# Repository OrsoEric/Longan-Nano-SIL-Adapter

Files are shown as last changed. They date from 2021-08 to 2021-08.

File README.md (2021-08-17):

# Longan-Nano-SIL-Adapter
SIL Adapter for the Longan Nano evaluation board for the GD32VF103. Allows vertical mounting for the board. Includes RS485 communication with 3.5mm Audio Jacks.

**Connector Pinout**  


**Schematics**  
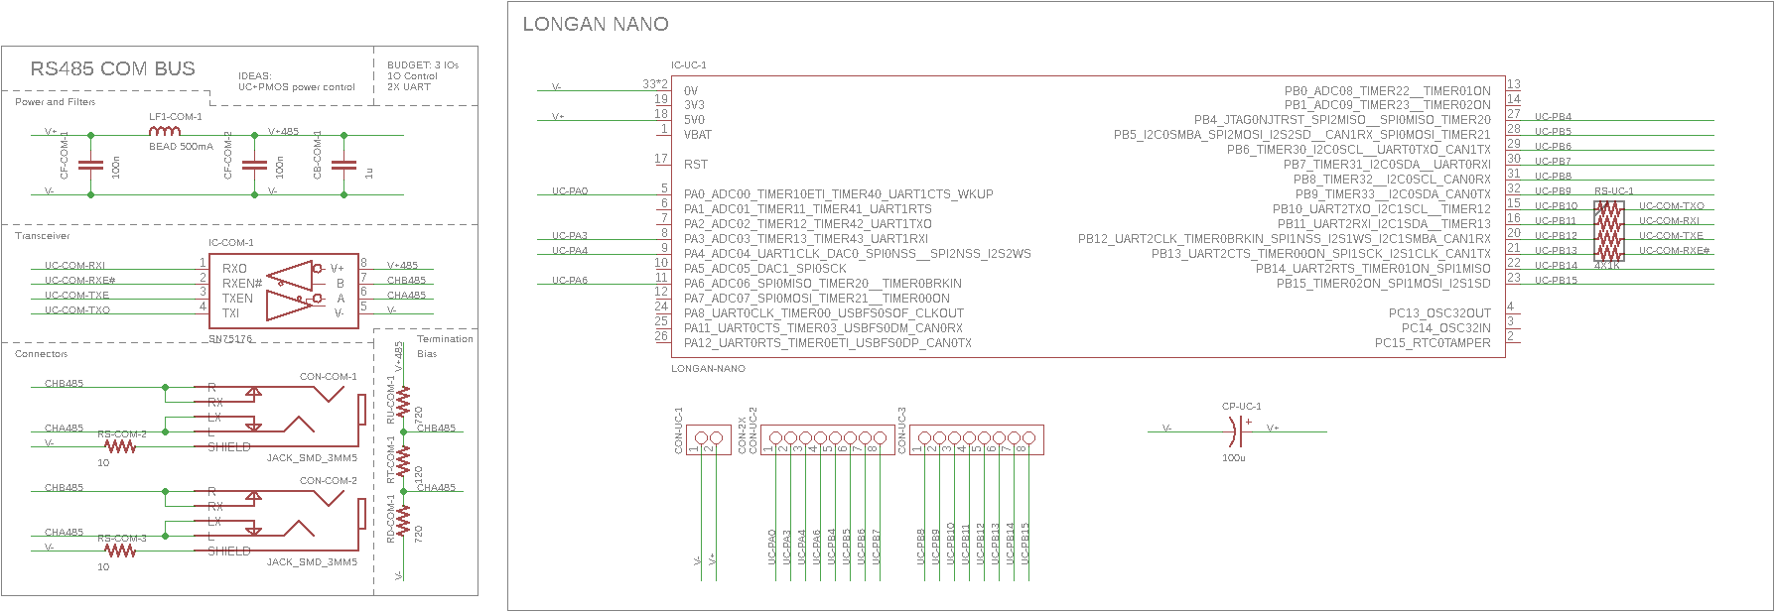
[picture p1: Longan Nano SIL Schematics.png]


**Routing**  


**Gerber**  
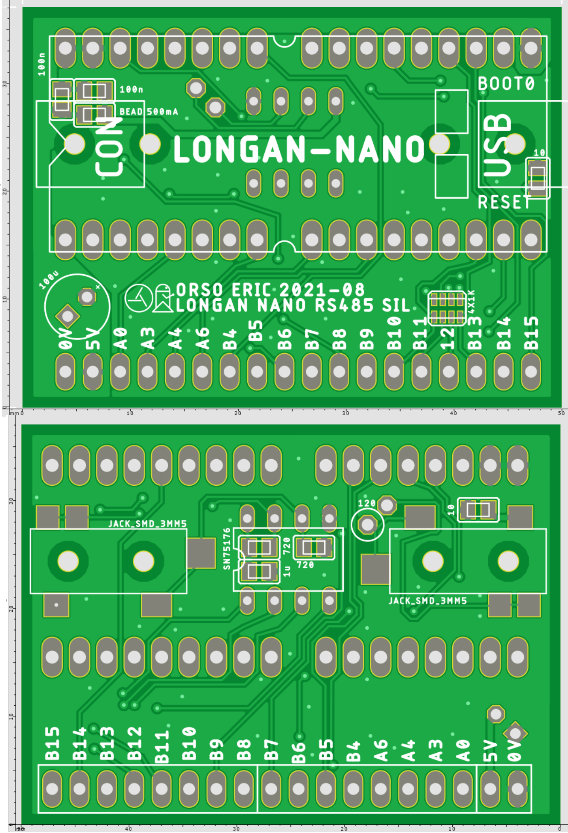
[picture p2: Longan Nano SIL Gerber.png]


**BOM**
*Part* 	*Value*  
CB-COM-1 	1u  
CF-COM-1 	100n  
CF-COM-2 	100n  
CON-COM-1 	JACK_SMD_3MM5  
CON-COM-2 	JACK_SMD_3MM5  
CON-UC-1 	2X2.54mm Male  
CON-UC-2 	8X2.54mm Male  
CON-UC-3 	8X2.54mm Male  
CP-UC-1 	100u  
IC-COM-1 	SN75176  
IC-UC-1 	LONGAN-NANO  
LF1-COM-1 	BEAD 500mA  
RD-COM-1 	720  
RS-COM-2 	10  
RS-COM-3 	10  
RS-UC-1 	4X1K  
RT-COM-1 	120  
RU-COM-1 	720

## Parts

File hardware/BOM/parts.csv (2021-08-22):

Part | Value | Device | Package | Description | MF | MPN | OC_FARNELL | OC_NEWARK
CB-COM-1 | 1u | C-M2012 | SMD-M2012 | Capacitor
CF-COM-1 | 100n | C-M2012 | SMD-M2012 | Capacitor
CF-COM-2 | 100n | C-M2012 | SMD-M2012 | Capacitor
CON-COM-1 | JACK_SMD_3MM5 | JACK_SMD_3MM5 | JACK_SMD_3MM5 | Jack 3.5mm
CON-COM-2 | JACK_SMD_3MM5 | JACK_SMD_3MM5 | JACK_SMD_3MM5 | Jack 3.5mm
CON-UC-1 | 2X2.54mm Male | CON-2X | TH-2X2.54 | Generic connector two pins
CON-UC-2 | 8X2.54mm Male | CON-8X | TH-8X2.54 | PIN HEADER
CON-UC-3 | 8X2.54mm Male | CON-8X | TH-8X2.54 | PIN HEADER
CP-UC-1 | 100u | C+-TH2.54-6.0 | TH-BARREL-2M54-6M0 | Polarized Capacitor
IC-COM-1 | SN75176 | RS485 | DIL08 | RS485 TRANSEIVER |  | MAX481CPA+ | unknown | 99K3445
IC-UC-1 | LONGAN-NANO | LONGAN-NANO | LONGAN-NANO | Longan Nano
LF1-COM-1 | BEAD 500mA | L-M2012 | SMD-M2012 | Inductor
RD-COM-1 | 720 | R-M2012 | SMD-M2012 | Resistor
RS-COM-2 | 10 | R-M2012 | SMD-M2012 | Resistor
RS-COM-3 | 10 | R-M2012 | SMD-M2012 | Resistor
RS-UC-1 | 4X1K | RX4-M2012-X4 | SMD-M2012-X4 | Four Resistor
RT-COM-1 | 120 | R-V2.54-3.0 | TH-LINE-2M54-3M0 | Resistor
RU-COM-1 | 720 | R-M2012 | SMD-M2012 | Resistor

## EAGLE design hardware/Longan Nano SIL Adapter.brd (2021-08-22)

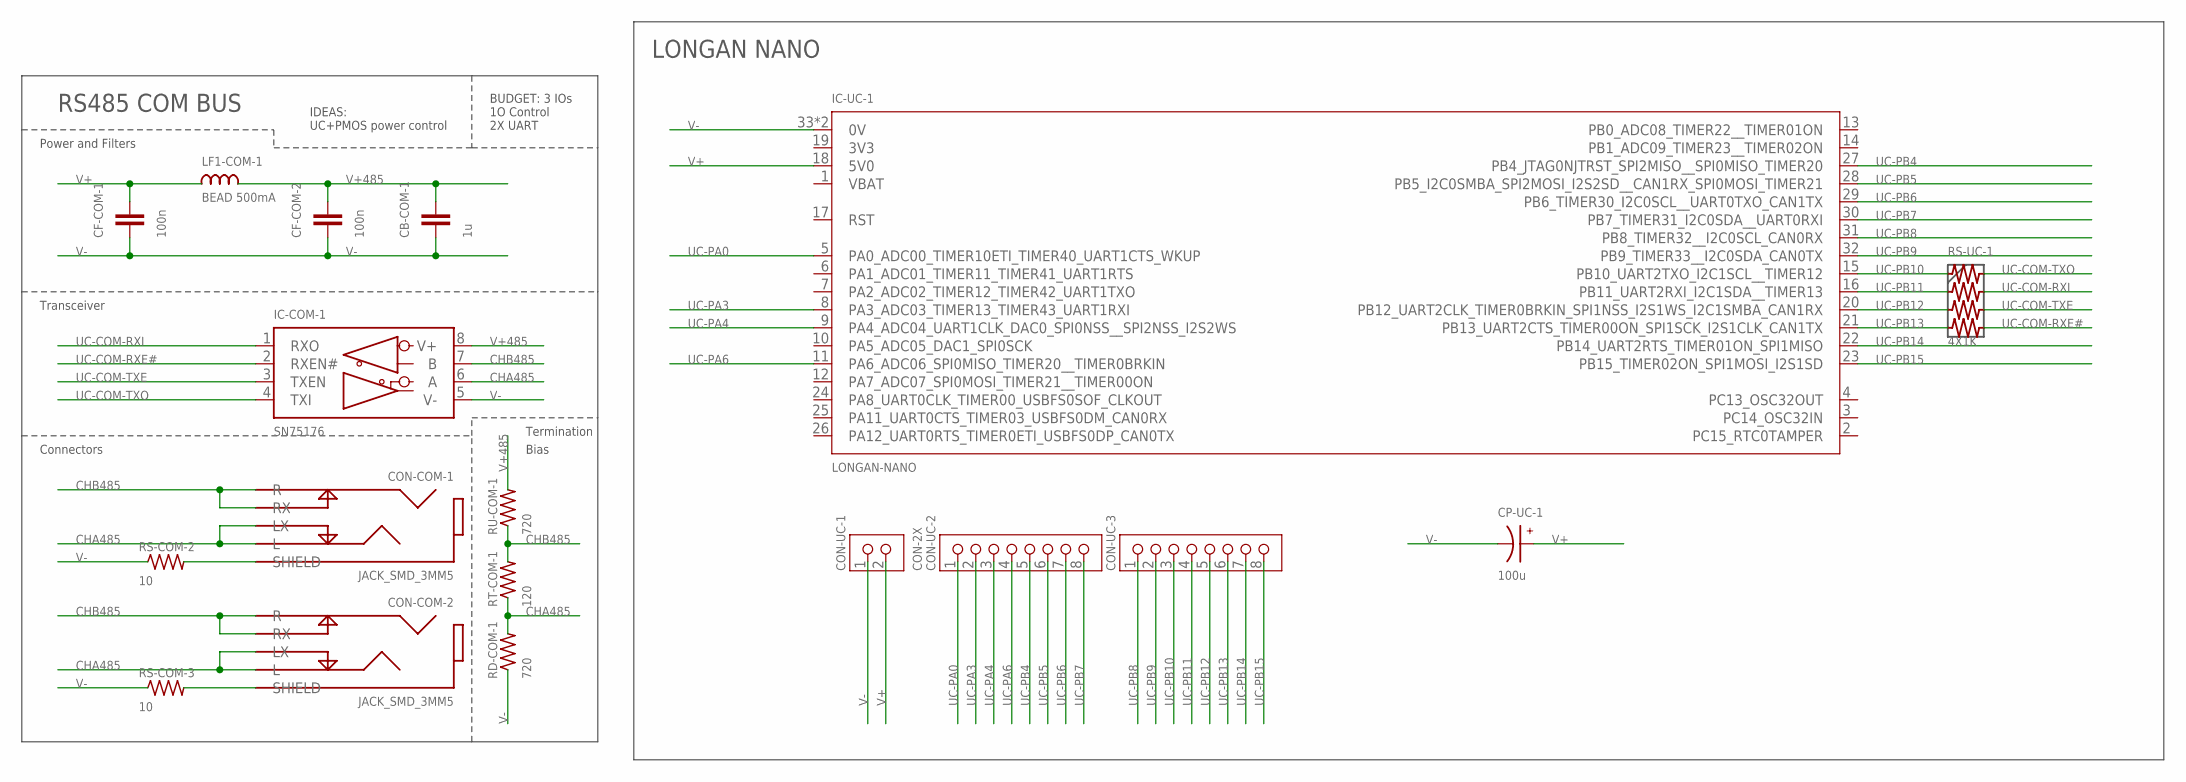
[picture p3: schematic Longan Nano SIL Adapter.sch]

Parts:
CB-COM-1: 1u; SMD-M2012
CF-COM-1, CF-COM-2: 100n; SMD-M2012
CON-COM-1, CON-COM-2: JACK_SMD_3MM5
CON-UC-1: CON-2X; TH-2X2.54
CON-UC-2, CON-UC-3: CON-8X; TH-8X2.54
CP-UC-1: 100u; TH-BARREL-2M54-6M0
IC-COM-1: SN75176; DIL08
IC-UC-1: LONGAN-NANO
LF1-COM-1: BEAD 500mA; SMD-M2012
RD-COM-1: 720; SMD-M2012
RS-COM-2, RS-COM-3: 10; SMD-M2012
RS-UC-1: 4X1K; SMD-M2012-X4
RT-COM-1: 120; TH-LINE-2M54-3M0
RU-COM-1: 720; SMD-M2012

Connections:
3V3: IC-UC-1.19 (3V3)
CHA485: CON-COM-1.L, CON-COM-1.LX, CON-COM-2.L, CON-COM-2.LX, IC-COM-1.6 (A), RD-COM-1.2, RT-COM-1.P$1 (1)
CHB485: CON-COM-1.R, CON-COM-1.RX, CON-COM-2.R, CON-COM-2.RX, IC-COM-1.7 (B), RT-COM-1.P$2 (2), RU-COM-1.1
unnamed: CON-COM-1.SHIELD, RS-COM-2.2
unnamed: CON-COM-2.SHIELD, RS-COM-3.2
UC-COM-RXE#: IC-COM-1.2 (RXEN#), RS-UC-1.4B
UC-COM-RXI: IC-COM-1.1 (RXO), RS-UC-1.2B
UC-COM-TXE: IC-COM-1.3 (TXEN), RS-UC-1.3B
UC-COM-TXO: IC-COM-1.4 (TXI), RS-UC-1.1B
UC-PA0: CON-UC-2.1, IC-UC-1.5 (PA0_ADC00_TIMER10ETI_TIMER40_UART1CTS_W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)
UC-PA3: CON-UC-2.2, IC-UC-1.8 (PA3_ADC03_TIMER13_TIMER43_UART1RXI)
UC-PA4: CON-UC-2.3, IC-UC-1.9 (PA4_ADC04_UART1CLK_DAC0_SPI0NSS__SPI2NS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)
UC-PA6: CON-UC-2.4, IC-UC-1.11 (PA6_ADC06_SPI0MISO_TIMER20__TIMER0BRKIN)
UC-PB4: CON-UC-2.5, IC-UC-1.27 (PB4_JTAG0NJTRST_SPI2MISO__SPI0MISO_TIME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)
UC-PB5: CON-UC-2.6, IC-UC-1.28 (PB5_I2C0SMBA_SPI2MOSI_I2S2SD__CAN1RX_SP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)
UC-PB6: CON-UC-2.7, IC-UC-1.29 (PB6_TIMER30_I2C0SCL__UART0TXO_CAN1TX)
UC-PB7: CON-UC-2.8, IC-UC-1.30 (PB7_TIMER31_I2C0SDA__UART0RXI)
UC-PB8: CON-UC-3.1, IC-UC-1.31 (PB8_TIMER32__I2C0SCL_CAN0RX)
UC-PB9: CON-UC-3.2, IC-UC-1.32 (PB9_TIMER33__I2C0SDA_CAN0TX)
UC-PB10: CON-UC-3.3, IC-UC-1.15 (PB10_UART2TXO_I2C1SCL__TIMER12), RS-UC-1.1A
UC-PB11: CON-UC-3.4, IC-UC-1.16 (PB11_UART2RXI_I2C1SDA__TIMER13), RS-UC-1.2A
UC-PB12: CON-UC-3.5, IC-UC-1.20 (PB12_UART2CLK_TIMER0BRKIN_SPI1NSS_I2S1W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), RS-UC-1.3A
UC-PB13: CON-UC-3.6, IC-UC-1.21 (PB13_UART2CTS_TIMER00ON_SPI1SCK_I2S1CLK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), RS-UC-1.4A
UC-PB14: CON-UC-3.7, IC-UC-1.22 (PB14_UART2RTS_TIMER01ON_SPI1MISO)
UC-PB15: CON-UC-3.8, IC-UC-1.23 (PB15_TIMER02ON_SPI1MOSI_I2S1SD)
V+: CF-COM-1.2, CON-UC-1.2, CP-UC-1.+, IC-UC-1.18 (5V0), LF1-COM-1.1
V+485: CB-COM-1.2, CF-COM-2.2, IC-COM-1.8 (V+), LF1-COM-1.2, RU-COM-1.2
V-: CB-COM-1.1, CF-COM-1.1, CF-COM-2.1, CON-UC-1.1, CP-UC-1.-, IC-COM-1.5 (V-), IC-UC-1.33 (0V), IC-UC-1.34 (0V), RD-COM-1.1, RS-COM-2.1, RS-COM-3.1
VBAT: IC-UC-1.1 (VBAT)

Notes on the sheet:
RS485 COM BUS
Power and Filters
Transceiver
Connectors
Termination
Bias
BUDGET: 3 IOs 1O Control 2X UART
IDEAS: UC+PMOS power control
LONGAN NANO

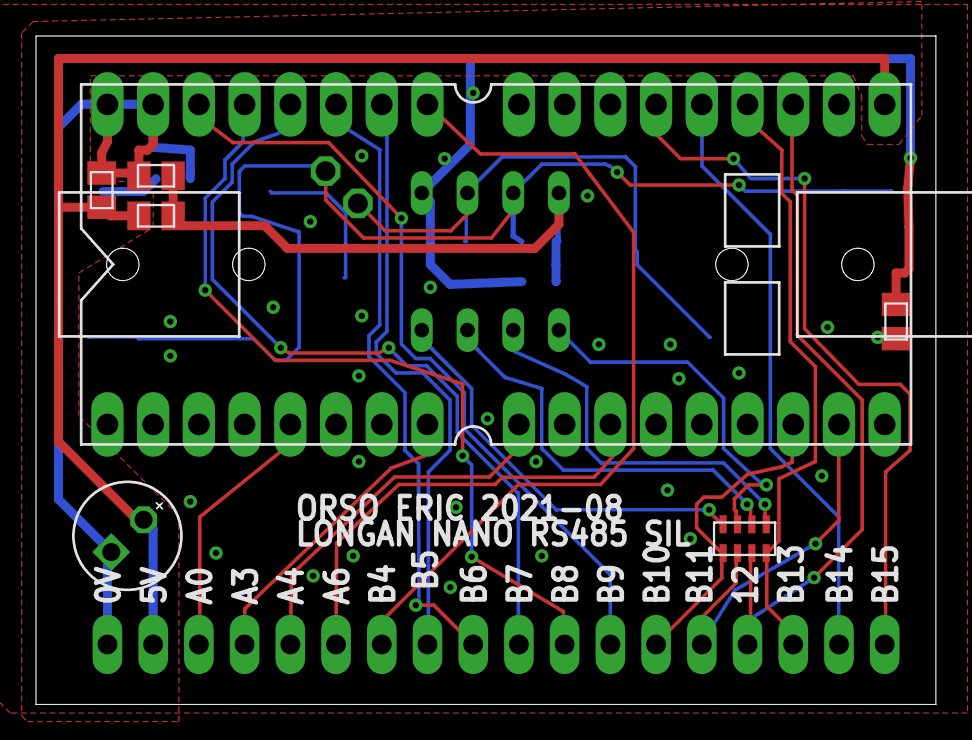
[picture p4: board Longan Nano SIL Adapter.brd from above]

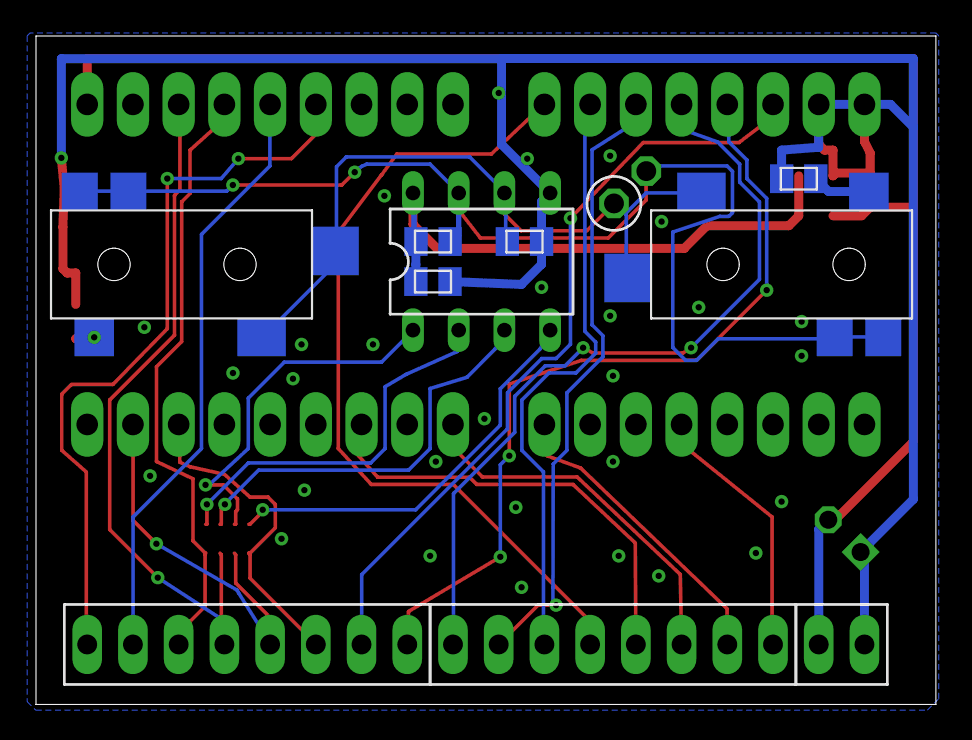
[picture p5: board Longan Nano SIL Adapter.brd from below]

Board: 2 copper layers, 50.0 x 37.1 mm, 20 parts (11 on the bottom side), 27 nets.

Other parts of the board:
U$1: SIGNATURE_ADROBOT_SMALL
U$2: SIGNATURE_ORANGEBOT_SMALL

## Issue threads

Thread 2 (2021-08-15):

Schematics - Microcontroller Pin Assignment

OrsoEric, 2021-08-15:
Carry out the green and orange pins to the connector. Leave the red pins (internally used by longan nano) alone. This allows for 16IOs and 2 Power pins on the SIL connector.
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

Closed 2021-08-15.

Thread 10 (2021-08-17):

Testing

OrsoEric, 2021-08-17:
- [ ] BOM
- [ ] Assembly PCB
- [ ] Test PCB
- [ ] Test Firmware

OrsoEric, 2021-08-17:
BOM

<HTML>
<HEAD>

	<META HTTP-EQUIV="CONTENT-TYPE" CONTENT="text/html; charset=utf-8">
	<TITLE></TITLE>
	<META NAME="GENERATOR" CONTENT="OpenOffice 4.0.1  (Win32)">
	<STYLE>
		<!--
		BODY,DIV,TABLE,THEAD,TBODY,TFOOT,TR,TH,TD,P { font-family:"Arial"; font-size:x-small }
		 -->
	</STYLE>

</HEAD>

<BODY TEXT="#000000">
<TABLE FRAME=VOID CELLSPACING=0 COLS=2 RULES=NONE BORDER=0>
	<COLGROUP><COL WIDTH=88><COL WIDTH=129></COLGROUP>
	<TBODY>
		<TR>
			<TD WIDTH=88 HEIGHT=17 ALIGN=LEFT>Part</TD>
			<TD WIDTH=129 ALIGN=LEFT>Value</TD>
		</TR>
		<TR>
			<TD HEIGHT=17 ALIGN=LEFT>CB-COM-1</TD>
			<TD ALIGN=LEFT>1u</TD>
		</TR>
		<TR>
			<TD HEIGHT=17 ALIGN=LEFT>CF-COM-1</TD>
			<TD ALIGN=LEFT>100n</TD>
		</TR>
		<TR>
			<TD HEIGHT=17 ALIGN=LEFT>CF-COM-2</TD>
			<TD ALIGN=LEFT>100n</TD>
		</TR>
		<TR>
			<TD HEIGHT=17 ALIGN=LEFT>CON-COM-1</TD>
			<TD ALIGN=LEFT>JACK_SMD_3MM5</TD>
		</TR>
		<TR>
			<TD HEIGHT=17 ALIGN=LEFT>CON-COM-2</TD>
			<TD ALIGN=LEFT>JACK_SMD_3MM5</TD>
		</TR>
		<TR>
			<TD HEIGHT=17 ALIGN=LEFT>CON-UC-1</TD>
			<TD ALIGN=LEFT>2X2.54mm Male</TD>
		</TR>
		<TR>
			<TD HEIGHT=17 ALIGN=LEFT>CON-UC-2</TD>
			<TD ALIGN=LEFT>8X2.54mm Male</TD>
		</TR>
		<TR>
			<TD HEIGHT=17 ALIGN=LEFT>CON-UC-3</TD>
			<TD ALIGN=LEFT>8X2.54mm Male</TD>
		</TR>
		<TR>
			<TD HEIGHT=17 ALIGN=LEFT>CP-UC-1</TD>
			<TD ALIGN=LEFT>100u</TD>
		</TR>
		<TR>
			<TD HEIGHT=17 ALIGN=LEFT>IC-COM-1</TD>
			<TD ALIGN=LEFT>SN75176</TD>
		</TR>
		<TR>
			<TD HEIGHT=17 ALIGN=LEFT>IC-UC-1</TD>
			<TD ALIGN=LEFT>LONGAN-NANO</TD>
		</TR>
		<TR>
			<TD HEIGHT=17 ALIGN=LEFT>LF1-COM-1</TD>
			<TD ALIGN=LEFT>BEAD 500mA</TD>
		</TR>
		<TR>
			<TD HEIGHT=17 ALIGN=LEFT>RD-COM-1</TD>
			<TD ALIGN=RIGHT SDVAL="720" SDNUM="2057;">720</TD>
		</TR>
		<TR>
			<TD HEIGHT=17 ALIGN=LEFT>RS-COM-2</TD>
			<TD ALIGN=RIGHT SDVAL="10" SDNUM="2057;">10</TD>
		</TR>
		<TR>
			<TD HEIGHT=17 ALIGN=LEFT>RS-COM-3</TD>
			<TD ALIGN=RIGHT SDVAL="10" SDNUM="2057;">10</TD>
		</TR>
		<TR>
			<TD HEIGHT=17 ALIGN=LEFT>RS-UC-1</TD>
			<TD ALIGN=LEFT>4X1K</TD>
		</TR>
		<TR>
			<TD HEIGHT=17 ALIGN=LEFT>RT-COM-1</TD>
			<TD ALIGN=RIGHT SDVAL="120" SDNUM="2057;">120</TD>
		</TR>
		<TR>
			<TD HEIGHT=17 ALIGN=LEFT>RU-COM-1</TD>
			<TD ALIGN=RIGHT SDVAL="720" SDNUM="2057;">720</TD>
		</TR>
	</TBODY>
</TABLE>
</BODY>

</HTML>

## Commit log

2021-08-15 Uploads Eagle Project
    [Longan Nano SIL Adapter.brd, Longan Nano SIL Adapter.sch]
2021-08-15 adds connector pinout to readme
2021-08-17 adds image of full schematics
2021-08-17 adds Gerber Files
2021-08-17 adds image of gerber production files
2021-08-17 final schematics and routing
    [Longan Nano SIL Adapter.brd, Longan Nano SIL Adapter.sch]
2021-08-17 updates readme with final schematics, routing and gerber.
2021-08-17 adds BOM
2021-08-22 updates production schematic, pcb and gerber. adds part list.
    [Longan Nano SIL Adapter.brd, Longan Nano SIL Adapter.sch, parts.csv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]
